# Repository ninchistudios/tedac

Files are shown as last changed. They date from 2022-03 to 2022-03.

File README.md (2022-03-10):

# AH-64D Apache TEDAC Project Files

This project contains my personal Fusion 360, Arduino and other files used to build a "close enough" replica TEDAC for the AH-64D Apache.

It is intended to be used with [DCS-BIOS](https://github.com/DCSFlightpanels/dcs-bios) to interface to the [DCS World Apache](https://www.digitalcombatsimulator.com/en/products/helicopters/ah-64d/).  The design is to suit my use case, which is something that looks cool and is functional & intuitive in VR. It's not trying to be a perfect replica for non-VR use.

Note that I am not a CAD/CAM professional, and am no longer a professional software developer. No support is provided and there is no guarantee that my files don't suck. To be very clear: I am sharing my personal files so that others can get a headstart. I am not presenting this as a product that I will be supporting or building commercially. Fork it and have fun.

## Compromises

Some compromises have been made as follows:

* The TEDAC faceplate DAY/NT/OFF rotary switch has been replaced with a rotary encoder. I just couldn't find a rotary selector switch small enough to fit.
* The TEDAC LCD used is a smaller 5" 800x480 display as that's what I had on hand. As I'm only using the TEDAC with VR, the LCD is not in use during gameplay so is really only there for cool factor and debug information.  
* The structural mount is designed as a 12mm ply box to fit my cockpit. You will most likely have to design your own structural element to suit your situation. The TEDAC itself is designed into 3 functional parts - faceplate and left/right grips - which can be mounted as you need and can be disconnected individually for maintenance.

## Hardware

You will need the following parts:

### Faceplate
* 21 x 6mm THT tactile button (I used 10mm stalk)
* 3 x 15mm THT rotary encoder EC11 (I used 20mm half handle)

### Left Grip

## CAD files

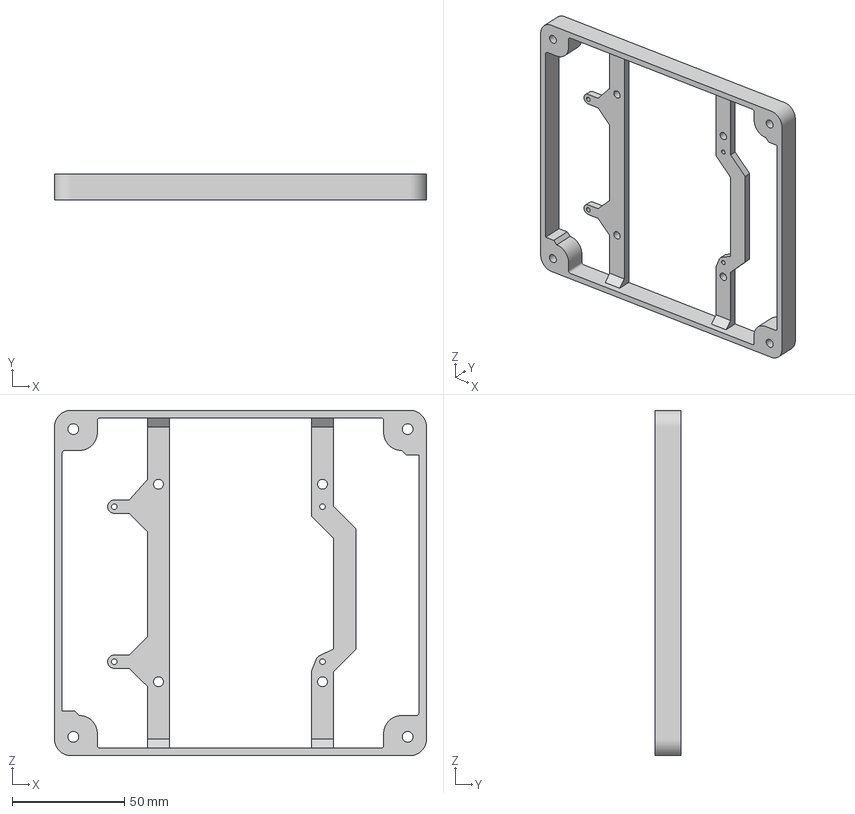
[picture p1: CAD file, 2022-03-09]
cadcam/Structural/LCDOuterPlate.3mf
165.8 x 11.8 x 154.0 mm

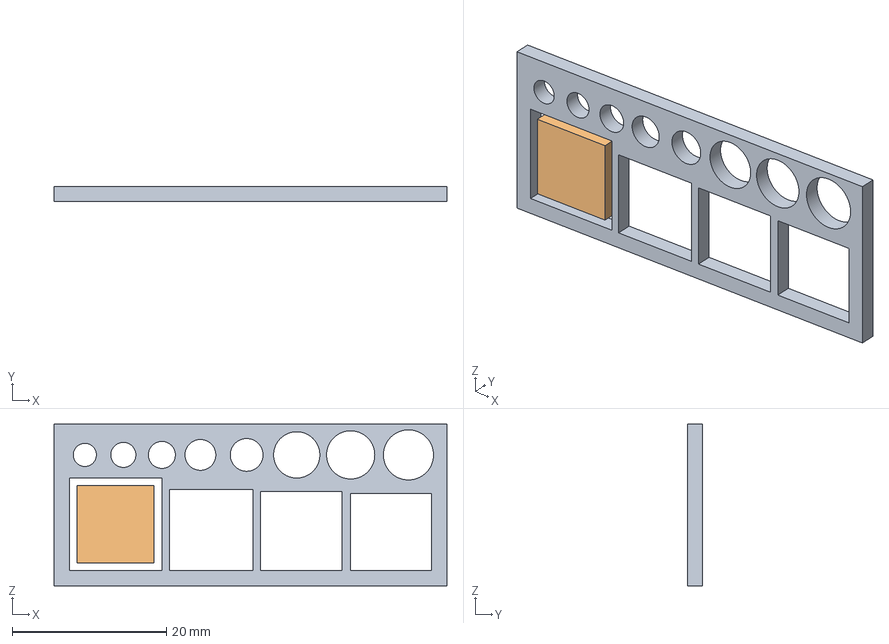
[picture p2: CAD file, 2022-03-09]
cadcam/tools/ToleranceTool.3mf
51.0 x 2.00 x 21.0 mm

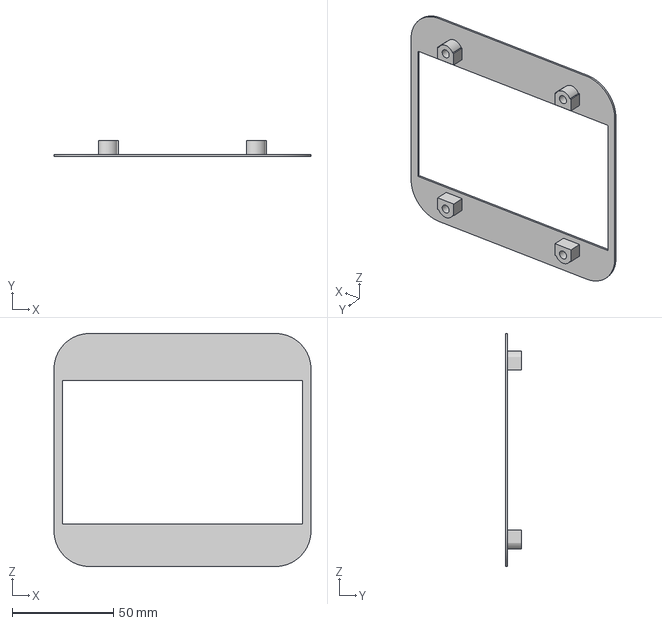
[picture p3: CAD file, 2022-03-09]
cadcam/Structural/LCDFaceplate.3mf
126.9 x 7.80 x 115.1 mm

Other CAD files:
cadcam/tools/ToleranceTool.f3d
cadcam/tools/ToleranceTool.stl

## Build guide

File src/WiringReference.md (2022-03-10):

# TEDAC Wiring Reference

## Conventions

TEDAC buttons/switches are named left to right, top to bottom on their respective devices. For example:

* TFP-T1MP TEDAC Faceplate, Top row position 1 (left) momentary press
* TFP-L2RP TEDAC Faceplate, Left row postion 2 (2nd from top), rotary press
* TFP-L2R[ABC] TEDAC Faceplate, Left row postion 2 (2nd from top), rotary encoder pin A, B or C
* all matrixed pins on a specific faceplate PCB are on the same row for ease of wiring
* TGL-01BMP TEDAC Grip Left, input 01 (button) momentary press
* TGL-02SM[FA] TEDAC Grip Left, input 02 (switch) momentary forward/aft
* TGL-03HM[FALRP] TEDAC Grip Left, input 03 (hat) momentary forward/aft/left/right/press
* TGL-04S[FCA] TEDAC Grip Left, input 04 (switch) forward/center/aft
* TGL-06J[XYP] TEDAC Grip Left, input 06 (joystick) X/Y/press

All matrix pins on a specific grip switch are on the same matrix row for ease of wiring

## Input Lists

### Faceplate

| P.PIN | FUNCTION | P.HDR | MATRIX ROW/COL | M.HDR | MEGA PIN(S) |
| --- | --- | --- | --- | ----- | --- |
| TFP-T1MP | TAD | JP1-TOP | 1-1 | TFPT  | |
| TFP-T2MP | FCR | JP1-TOP | 1-2 | TFPT  | |
| TFP-T3MP | PNV | JP1-TOP | 1-3 | TFPT  | |
| TFP-T4MP | G/S | JP1-TOP | 1-4 | TFPT  | |
| TFP-T5RP | DayNtOff NF | JP1-TOP | 1-5 | TFPT  | |
| TFP-T5RA | DayNtOff A  | JST1-TOP  | - | TFP01 | |
| TFP-T5RB | DayNtOff B  | JST1-TOP  | - | TFP01 | |
| TFP-T5RC | DayNtOff C  | JST1-TOP  | - | TFP01 | |
| TFP-L1RP | LEV NF | JP2-LEFT  | 2-1 | TFPL  | |
| TFP-L1RA | LEV A | JST2-LEFT | - | TFP02 | |
| TFP-L1RB | LEV B | JST2-LEFT | - | TFP02 | |
| TFP-L1RC | LEV C | JST2-LEFT | - | TFP02 | |
| TFP-L2RP | GAIN NF | JP2-LEFT  | 2-2 | TFPL  | |
| TFP-L2RA | GAIN A | JST3-LEFT | - | TFP03 | |
| TFP-L2RB | GAIN B | JST3-LEFT | - | TFP03 | |
| TFP-L2RC | GAIN C | JST3-LEFT | - | TFP03 | |
| TFP-L3MP | R/F UP | JP3-LEFT  | 2-3 | TFPL  | |
| TFP-L4MP | R/F DOWN | JP3-LEFT  | 2-4 | TFPL  | |
| TFP-L5MP | EL UP | JP3-LEFT  | 2-5 | TFPL  | |
| TFP-L6MP | EL DOWN | JP3-LEFT  | 2-6 | TFPL  | |
| TFP-R1MP | SYM UP | JP4-RIGHT | 3-1 | TFPR  | |
| TFP-R2MP | SYM DOWN | JP4-RIGHT | 3-2 | TFPR  | |
| TFP-R3MP | BRT UP | JP4-RIGHT | 3-3 | TFPR  | |
| TFP-R4MP | BRT DOWN | JP4-RIGHT | 3-4 | TFPR  | |
| TFP-R5MP | CON UP | JP5-RIGHT | 3-5 | TFPR  | |
| TFP-R6MP | CON DOWN | JP5-RIGHT | 3-6 | TFPR  | |
| TFP-R7MP | * DEFAULT | JP5-RIGHT | 3-7 | TFPR  | |
| TFP-B1MP | AZ LEFT | JP6-BOT | 4-1 | TFPB  | |
| TFP-B2MP | AZ RIGHT | JP6-BOT | 4-2 | TFPB  | |
| TFP-B3MP | MULTI B1 | JP6-BOT | 4-3 | TFPB  | |
| TFP-B4MP | MULTI B2 | JP7-BOT | 4-4 | TFPB  | |
| TFP-B5MP | MULTI B3 | JP7-BOT | 4-5 | TFPB  | |
| TFP-B6MP | MULTI B4 | JP7-BOT | 4-6 | TFPB  | |

### Grip Left

| P.PIN | FUNCTION | P.HDR | MATRIX ROW/COL | M.HDR | MEGA PIN(S) |
| --- | --- | ----- | --- | ----- | --- |
| TGL-01BMP | VIDEO REC | - | | TGL01 | |
| TGL-02SMF | IAT EN/ACT  | - | | TGL02 | |
| TGL-02SMA | IAT OFS | - | | TGL02 | |
| TGL-03HMF | TADS FOV Z  | - | | TGL03 | |
| TGL-03HMA | TADS FOV M  | - | | TGL03 | |
| TGL-03HML | TADS FOV N  | - | | TGL03 | |
| TGL-03HMR | TADS FOV W  | - | | TGL03 | |
| TGL-03HMP | TADS FOV NF | - | | TGL03 | |
| TGL-04SF  | SSEL FLIR | - | | TGL04 | |
| TGL-04SC  | SSEL DTV | - | | TGL04 | |
| TGL-04SA  | SSEL DVO NF | - | | TGL04 | |
| TGL-05HMF | FCR GTM | - | | TGL05 | |
| TGL-05HMA | FCR ATM | - | | TGL05 | |
| TGL-05HML | FCR TPM | - | | TGL05 | |
| TGL-05HMR | FCR RMAP | - | | TGL05 | |
| TGL-05HMP | FCR NF | - | | TGL05 | |
| TGL-06JX  | CURSOR X | - | | TGL06 | |
| TGL-06JY  | CURSOR Y | - | | TGL06 | |
| TGL-06JP  | CURSOR ENT  | - | | TGL06 | |
| TGL-07HMF | WAS G | - | | TGL07 | |
| TGL-07HMA | WAS A NF | - | | TGL07 | |
| TGL-07HML | WAS R | - | | TGL07 | |
| TGL-07HMR | WAS M | - | | TGL07 | |
| TGL-07HMP | WAS NF | - | | TGL07 | |
| TGL-08BMP | CURSOR L/R  | - | | TGL08 | |
| TGL-09SMF | POS STORE | - | | TGL09 | |
| TGL-09SMA | POS UPD | - | | TGL09 | |
| TGL-10BMP | WPN TRIG | - | | TGL10 | |
| TGL-11SMF | FCR S-SCAN  | - | | TGL11 | |
| TGL-11SMA | FCR C-SCAN  | - | | TGL11 | |
| TGL-12BMP | CUED | - | | TGL12 | |
| TGL-13BMP | CAGE NF | - | | TGL13 | |
| TGL-14BMP | LMC | - | | TGL14 | |

### Grip Right

| P.PIN | FUNCTION | P.HDR | MATRIX ROW/COL | M.HDR | MEGA PIN(S) |
| --- | --- | ----- | --- | ----- | --- |
| TGR-01SF | LST MODE A | - | | TGR01 | |
| TGR-01SC | LST MODE O | - | | TGR01 | |
| TGR-01SA | LST MODE M | - | | TGR01 | |
| TGR-02HMF  | FCR SCAN Z | - | | TGR02 | |
| TGR-02HMA  | FCR SCAN M | - | | TGR02 | |
| TGR-02HML  | FCR SCAN N | - | | TGR02 | |
| TGR-02HMR  | FCR SCAN W | - | | TGR02 | |
| TGR-02HMP  | FCR SCAN NF | - | | TGR02 | |
| TGR-03BMP  | C-SCOPE | - | | TGR03 | |
| TGR-04BMP  | FLIR POL | - | | TGR04 | |
| TGR-05SF | IAT POL W | - | | TGR05 | |
| TGR-05SC | IAT POL A | - | | TGR05 | |
| TGR-05SA | IAT POL B | - | | TGR05 | |
| TGR-06HMF  | SIGHT HMD | - | | TGR06 | |
| TGR-06HMA  | SIGHT LINK | - | | TGR06 | |
| TGR-06HML  | SIGHT FCR | - | | TGR06 | |
| TGR-06HMR  | SIGHT TADS | - | | TGR06 | |
| TGR-06HMP  | SIGHT NF | - | | TGR06 | |
| TGR-07JX | TFC X | - | | TGR07 | |
| TGR-07JY | TFC Y | - | | TGR07 | |
| TGR-07JP | TFC NF | - | | TGR07 | |
| TGR-08BMP  | SIGHT SLAVE | - | | TGR08 | |
| TGR-09BMP  | FCR ZOOM | - | | TGR09 | |
| TGR-10BMP1 | LRFD TRIG DET 1 | - | | TGR10 | |
| TGR-10BMP2 | LRFD TRIG DET 2 | - | | TGR10 | |
| TGR-11SMF  | MTT PROM NEXT | - | | TGR11 | |
| TGR-11SMA  | MTT PROM NEXT | - | | TGR11 | |
| TGR-12BMP  | CURSOR ENT | - | | TGR12 | |
| TGR-13BMP  | HDD NF | - | | TGR13 | |
| TGR-14BMP  | MSL ADV | - | | TGR14 | |

## Header List

| HEADER | TYPE | LOCATION | PURPOSE |
| --- | --- | --- | --- |
| JP1-TOP | 5x2 Dupont Male  | Faceplate Top PCB | Faceplate Top Buttons |
| JP2-LEFT  | 2x2 Dupont Male  | Faceplate Left PCB | Faceplate Left Rotary Buttons |
| JP3-LEFT  | 4x2 Dupont Male  | Faceplate Left PCB | Faceplate Left Buttons |
| JP4-RIGHT | 4x2 Dupont Male  | Faceplate Right PCB  | Faceplate Right Upper Buttons |
| JP5-RIGHT | 3x2 Dupont Male  | Faceplate Right PCB  | Faceplate Right Lower Buttons |
| JP6-BOT | 3x2 Dupont Male  | Faceplate Bottom PCB | Faceplate BottomL Buttons |
| JP7-BOT | 3x2 Dupont Male  | Faceplate Bottom PCB | Faceplate BottomR Buttons |
| JST1-TOP  | JST XH x3 | Faceplate Top PCB | Faceplate Rotary 1 |
| JST2-LEFT | JST XH x3 | Faceplate Left PCB | Faceplate Rotary 2 |
| JST3-LEFT | JST XH x3 | Faceplate Left PCB | Faceplate Rotary 3 |
| TFPT | 5x2 Dupont Male  | Master PCB | Master for Faceplate Top |
| TFPL | 6x2 Dupont Male  | Master PCB | Master for Faceplate Left |
| TFPR | 7x2 Dupont Male  | Master PCB | Master for Faceplate Right |
| TFPB | 6x2 Dupont Male  | Master PCB | Master for Faceplate Bottom |
| TFP01 | JST XH x3 | Master PCB | Master for Faceplate Rotary 1 |
| TFP02 | JST XH x3 | Master PCB | Master for Faceplate Rotary 2 |
| TFP03 | JST XH x3 | Master PCB | Master for Faceplate Rotary 3 |
| TGL01 | JST XH x2 | Master PCB | Master for Left Grip Switch 1 |
| TGL02 | JST XH x3 | Master PCB | Master for Left Grip Switch 2 |
| TGL03 | JST XH x6 | Master PCB | Master for Left Grip Switch 3 |
| TGL04 | JST XH x4 | Master PCB | Master for Left Grip Switch 4 |
| TGL05 | JST XH x6 | Master PCB | Master for Left Grip Switch 5 |
| TGL06 | JST XH x4 | Master PCB | Master for Left Grip Switch 6 |
| TGL07 | JST XH x6 | Master PCB | Master for Left Grip Switch 7 |
| TGL08 | JST XH x2 | Master PCB | Master for Left Grip Switch 8 |
| TGL09 | JST XH x3 | Master PCB | Master for Left Grip Switch 9 |
| TGL10 | JST XH x2 | Master PCB | Master for Left Grip Switch 10 |
| TGL11 | JST XH x3 | Master PCB | Master for Left Grip Switch 11 |
| TGL12 | JST XH x2 | Master PCB | Master for Left Grip Switch 12 |
| TGL13 | JST XH x2 | Master PCB | Master for Left Grip Switch 13 |
| TGL14 | JST XH x2 | Master PCB | Master for Left Grip Switch 14 |
| TGR01 | JST XH x4 | Master PCB | Master for Right Grip Switch 1 |
| TGR02 | JST XH x6 | Master PCB | Master for Right Grip Switch 2 |
| TGR03 | JST XH x2 | Master PCB | Master for Right Grip Switch 3 |
| TGR04 | JST XH x2 | Master PCB | Master for Right Grip Switch 4 |
| TGR05 | JST XH x4 | Master PCB | Master for Right Grip Switch 5 |
| TGR06 | JST XH x6 | Master PCB | Master for Right Grip Switch 6 |
| TGR07 | JST XH x4 | Master PCB | Master for Right Grip Switch 7 |
| TGR08 | JST XH x2 | Master PCB | Master for Right Grip Switch 8 |
| TGR09 | JST XH x2 | Master PCB | Master for Right Grip Switch 9 |
| TGR10 | JST XH x3 | Master PCB | Master for Right Grip Switch 10 |
| TGR11 | JST XH x3 | Master PCB | Master for Right Grip Switch 11 |
| TGR12 | JST XH x2 | Master PCB | Master for Right Grip Switch 12 |
| TGR13 | JST XH x2 | Master PCB | Master for Right Grip Switch 13 |
| TGR14 | JST XH x2 | Master PCB | Master for Right Grip Switch 14 |
| MATRIX | 10x2 Dupont Male | Master PCB | 10x10 Matrix Master to Mega |
| ENCS | 7x1 Dupont Male  | Master PCB | 6 + 1GND Rotary Enc Master to Mega |
| AXES | 5x1 Dupont Male  | Master PCB | 4 + 1GND Joystick Axes Master to Mega |

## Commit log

2022-03-09 LCD plates test prints
2022-03-10 initial wiring list, pending right grip
2022-03-10 master connectors
2022-03-10 wiring plan
2022-03-10 wiring updates
